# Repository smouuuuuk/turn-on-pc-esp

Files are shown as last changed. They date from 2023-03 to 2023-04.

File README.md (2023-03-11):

# Turning ON or OFF your PC using an ESP8266

I needed a way to turn my PC On from outside my house just in case I ever need to access a file.

Firstly, I considered using the WakeOnLan protocol which would be fairly easy to set up by using a Raspberry Pi or doing some port-forwarding in my home router.

I opted for a second option, at the time I was messing around with ESP microcontrollers and wanted to work with one of those. So I searched around for ways to do this and found [noisycarlos's video](https://www.youtube.com/watch?v=rV2b7UrGHbk&t=4s) which had a link to his [website](https://noisycarlos.com/project/how-to-turn-your-computer-on-and-off-remotely/) with code and a schematic for the circuit.

Much of the code is based on his code. I tweaked it a bit so instead of having to send commands to the ESP8266 I could do it through a WebServer hosted by the microcontroller and a few buttons on it. I also added comments to the code and changed a part of the circuit schematic.

I used an ESP8266 microcontroller that I had laying around, the D1 Mini NodeMCU ESP8266-12F from AZ-Delivery.

You first need to know how the pins on the motherboard work whenever you turn it on or reset it by pressing the buttons on your case.

When you press the power button on your PC's case it shortcircuits both power pins on the motherboard and that's when the PC turns ON. It's the same thing for the reset button. Knowing this I needed a way to make this connection by sending a signal from the ESP8266.

In his video, noisycarlos uses some optocouplers to make the shortcircuit between the pins but I decided I wanted to try using some relays, the mechanical part of it and the sound they make when they close the circuit is just that satisfying.

So I bought a few relays. I tested if first at the shop by hooking it up to two 1.5V batteries in series and it worked so I thought it would be fine with the 3.3V that come out of the microcontroller GPIO pins.

I plugged it into one of the GPIO pins and it didn't work, it did work on the 3.3V pin though. This happened because I didn't take into account the maximum current the GPIO pins can output (12mA) which is not enough to activate the relay.

After this I decided to use Optocouplers, these components are typically used in low power applications, and due to their non-mechanical nature they're usually longer lasting than a relay. Searching for one that would fit my requirements I ended up getting a few 4N25, which is able to operate with those 12mA coming from the GPIO pins.

For the power/reset pins I connect one of the GPIO pins to the input of the 4N25 and the other to GND. At the output I connect both cables that go to the motherboard pins. When I pull the GPIO pin to HIGH and current flows through the optocoupler both ends at the output are connected thus creating a shortcircuit, emulating a button press.

The principle for reading the state of the Power LED is the same but the other way around, the LED pins from the motherboard are the ones activating or deactivating the 4N25 and at the output of the IC I hava the 3.3V pin connected to one of the outputs of the IC and an Input pin from the ESP8266 at the other output, this way it knows when the LED light is ON or OFF.

# Connections

The pins I used are the following:
* D1 (GPIO5)  -  Pin used to read if the Power LED is ON or OFF
* D2 (GPIO4)  -  Pin used to turn ON or OFF the Power LED on the PC's case
* D5 (GPIO14) -  Pin used to activate the Reset signal for the PC
* D7 (GPIO13) -  Pin used to activate the Power signal for the PC

A diagram of the circuit can be seen here:

Final-Schematic

I've also made a custom PCB and a simple 3D case to enclose everything inside it. Feel free to tweak them however you like!

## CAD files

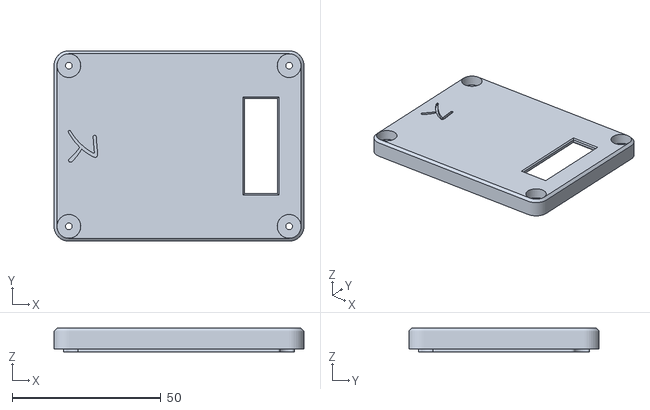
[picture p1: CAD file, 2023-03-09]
files/3D_Case/Tapa.stl
84.0 x 64.0 x 8.00

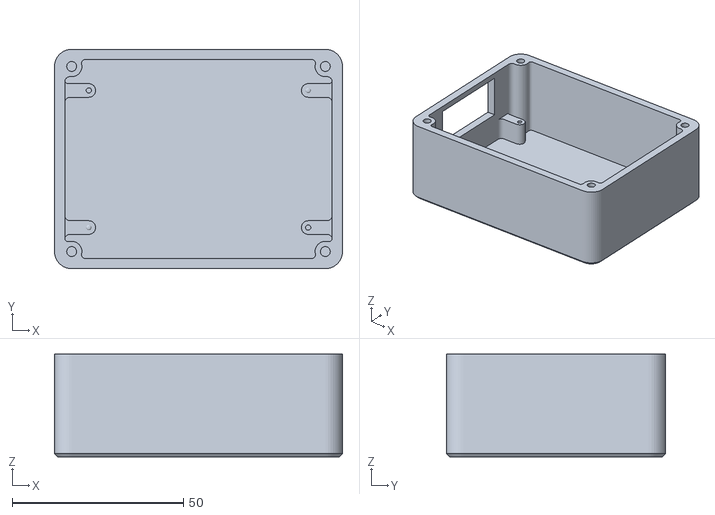
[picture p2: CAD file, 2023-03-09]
files/3D_Case/Caja.stl
84.0 x 64.0 x 30.0

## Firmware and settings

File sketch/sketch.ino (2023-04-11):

/* 
 * Turning on your PC using an ESP8266 Microcontroller
 * Created March 6, 2023 by Alexander Cabello
 */

#include <ESP8266WiFi.h>
#include <WiFiClient.h>
#include <ESP8266WebServer.h>
#include <ESP8266HTTPClient.h>
#include <ESP_Mail_Client.h>

#include "secrets.h"            // files with credentials, the following variables are taken from the secrets.h file:
                                // SECRET_SSID  - SSID from the AP used to connect to the Internet
                                // SECRET_PWD   - Password to access the network
                                // SECRET_REALM - 
                                // SECRET_LOGIN  - User to authenticate in the WebServer
                                // SECRET_PASS  - Password to authenticate in the WebServer

ESP8266WebServer server(80);    // WebServer will be hosted on port 80

WiFiClient wifiClient;

SMTPSession smtp;

const int powerButtonPin = 13,  // pins needed for the project
          resetButtonPin = 14,
          ledInPin = 5,
          ledOutPin = 4;

int powerPins[] = {powerButtonPin, resetButtonPin};   // pins that will act as the power and restart "buttons"

const int buttonNormalPressTime = 500,  // press the button for 500ms
          buttonForcePressTime = 5000;  // press the button for 5 seconds

int lastOn = 0,     // last time the LED light turned on (since the start)
    lastOff = 0;    // last time the LED light turned off (since the start)

int statePC = 0;    // 0=Off, 1=On, 2=Sleep

const String stateColors[] = {"#f03131", "#5cdf28", "#3743f0"};  // rgb colors in hexadecimal format that will represent the different states of the PC

int prevLightStatus = 0;       // 0=Off, 1=On, not the immediate value of the LED, will be useful to determine if there's been a change from its previous state

int timeToRelease = 0;         // time at which the currently pressed button will have to be released
int currentButtonPressed = 0;  // 0=Nothing, 1=Power On/Off/Force, 2=Reboot

String currentPublicIP = "";
const int waitTimeCheckIP = 4 * 3600 * 1000;  // will send and API request every 4 hours
int timeToCheckPublicIP = 0;   // time at which the API request will be sent

/**
 * "Presses" the button by putting the pin assigned to the power button to its HIGH state
 * Takes in one parameter - time - which defines for how long the power button will be pressed
 */
void pressPowerButton(int time){
  digitalWrite(powerPins[currentButtonPressed-1], HIGH);
  // the time at which the button will have to be released is stored
  timeToRelease = millis() + time;
}

/**
 * Does the same as the previous function but for the reset button by putting the pin assigned to the reset button to its HIGH state
 */
void pressResetButton(int time){
  digitalWrite(powerPins[currentButtonPressed-1], HIGH);
  timeToRelease = millis() + time;
}

/**
 * Checks if there is a pressed button and if the current time has reached the time at which the button has to be released
 * If so, the pin assigned to the pressed button is pulled to its LOW state
 */
void checkIfNeedToRelease(){
  if (currentButtonPressed && millis() >= timeToRelease){
    digitalWrite(powerPins[currentButtonPressed - 1], LOW);
    currentButtonPressed = 0;
  }
}

/**
 * Checks the present state of the Power LED Light coming from the Motherboard
 * Also stores the last time at which the LED turned ON or OFF (implying a transition from one to the other)
 */
void checkLEDPowerLight(){
  int stateLED = digitalRead(ledInPin);
  // outputs its current state to the output pin going to the LED of the button on the case
  digitalWrite (ledOutPin, stateLED);
  // if it's ON and it was OFF in its previous state
  if (stateLED && !prevLightStatus){
    lastOn = millis();
  // if it's OFF and it was ON in its previous state
  } else if (!stateLED && prevLightStatus) {
    lastOff = millis();
  }
  // current state stored for comparison in the next loop
  prevLightStatus = stateLED;
  checkStatusChange(stateLED);
}

/**
 * Checks the current state of the PC
 * The state can be one of the following: 0 (OFF), 1 (ON), 2 (SLEEP)
 * Takes one parameter - stateLED - which defines the current state of the LED
 */
void checkStatusChange(int stateLED){
  // necessary for when the code starts to run, otherwise it would define the state of the PC as SLEEP at the start
  if(lastOn != 0 && lastOff != 0){
    // if the LED has neither been ON or OFF for more than 4 seconds it must mean it's in SLEEP which goes from ON to OFF every second
    if((millis() < lastOn + 4000) && (millis() < lastOff + 4000)){
      // if the previous state is different then we announce the change it on the Serial Monitor
      if (statePC != 2) Serial.println("State: Sleep");
      statePC = 2;
      return;
    }
  }
  // if it's not in SLEEP it must be either ON or OFF
  // we can just use the current state on the LED to determine that
  if(stateLED){
    if (statePC != 1) Serial.println("State: On");
    statePC = 1;
  } else {
    if (statePC != 0) Serial.println("State: Off");
    statePC = 0;
  }
}

/**
 * Serves the root page to the client accessing the WebServer
 * Will vary the color of a small portion in the background indicating the current state of the PC
 */
void handleRoot(){
  // we include all of the html code on a String which will be sent to the client
  String rootPage;
  rootPage += "<html style=\"font-family:Arial,Helvetica,sans-serif; box-sizing: border-box; display: grid; place-items: center; height: 100vh; padding: 1em; background-color: ";
  rootPage += stateColors[statePC];
  rootPage += "\"> <head> <title>Manage PC</title> </head> <body style=\"height:100%;width:100%;display:grid;place-items:center;padding:0;margin:0; border: 1px solid black; background-color: white;\"> <a href=\"onoff\" style=\"font-size:3em;color:#000;text-decoration:none;height:100%;width:100%;border-bottom:2px solid #000;display:grid;place-items:center\" onmouseover='this.style.backgroundColor=\"#000000\",this.style.color=\"white\"' onmouseout='this.style.backgroundColor=\"\",this.style.color=\"black\"'>ON/OFF</a> <a href=\"reboot\" style=\"font-size:3em;color:#000;text-decoration:none;height:100%;width:100%;border-bottom:2px solid #000;display:grid;place-items:center\" onmouseover='this.style.backgroundColor=\"#000000\",this.style.color=\"white\"' onmouseout='this.style.backgroundColor=\"\",this.style.color=\"black\"'>RESTART</a> <a href=\"force\" style=\"font-size:3em;color:#000;text-decoration:none;height:100%;width:100%;border-bottom:2px solid #000;display:grid;place-items:center\" onmouseover='this.style.backgroundColor=\"#000000\",this.style.color=\"white\"' onmouseout='this.style.backgroundColor=\"\",this.style.color=\"black\"'>FORCE</a> </body> </html>";
  server.send(200, "text/html", rootPage);
}

/**
 * Serves the onoff page to the client accessing the WebServer
 * If no button is currently pressed it will call the function to press the Power Button to turn the PC ON or OFF
 * At the end, it redirects the client to the root page
 */
void handleOnOff(){
  server.sendHeader("Location", String("/"), true);
  if (!currentButtonPressed){
    currentButtonPressed = 1;
    pressPowerButton(buttonNormalPressTime);
  }
  server.send ( 302, "text/plain", "");
}

/**
 * Serves the reboot page to the client accessing the WebServer
 * If no button is currently pressed it will call the function to press the Reset Button
 * At the end, it redirects the client to the root page
 */
void handleReboot(){
  server.sendHeader("Location", String("/"), true);
  if (!currentButtonPressed){
    currentButtonPressed = 2;
    pressResetButton(buttonNormalPressTime);
  }
  server.send ( 302, "text/plain", "");
}

/**
 * Serves the force page to the client accessing the WebServer
 * If no button is currently pressed it will call the function to press the Power Button and hold it for the specified time
 * At the end, it redirects the client to the root page
 */
void handleForce(){
  server.sendHeader("Location", String("/"), true);
  if (!currentButtonPressed){
    currentButtonPressed = 1;
    pressPowerButton(buttonForcePressTime);
  }
  server.send ( 302, "text/plain", "");
}

/**
 * If the client tries to access a location that doesn't exist they will be redirected to the root page
 */
void handleNotFound(){
  server.sendHeader("Location", String("/"), true);
  server.send ( 302, "text/plain", "");
}

void checkIfNeedToCheckIP() {
  if (millis() >= timeToCheckPublicIP){
    HTTPClient http;
    http.begin(wifiClient, "https://api.ipify.org");
    int httpCode = http.GET();
    if (httpCode > 0) {
      String payload = http.getString();
      Serial.println(payload);
      if (payload != currentPublicIP){
        currentPublicIP = payload;
        notifyPublicIPChange(currentPublicIP);
    }
    http.end();
    }
    timeToCheckPublicIP += waitTimeCheckIP;
  }
}

void notifyPublicIPChange (String newIP){
  ESP_Mail_Session session;
  session.server.host_name = "smtp.gmail.com" ;
  session.server.port = 465;
  session.login.email = SECRET_EMAIL_SENDER;
  session.login.password = SECRET_APP_PASS;
  session.login.user_domain = "";
  
  SMTP_Message message;
  message.sender.name = "ESP8266";
  message.sender.email = SECRET_EMAIL_SENDER;
  message.subject = "ESP8266 Testing Email";
  message.addRecipient("Receiver",SECRET_EMAIL_RECIPIENT);
  String textMsg = newIP;
  message.text.content = textMsg.c_str();
  message.text.charSet = "us-ascii";
  message.text.transfer_encoding = Content_Transfer_Encoding::enc_7bit;

  if (!smtp.connect(&session)) return;
  if (!MailClient.sendMail(&smtp, &message)) Serial.println("Error sending Email, " + smtp.errorReason());
}

void setup(){
  Serial.begin(115200);
  Serial.println("");

  // pin initialization
  for (int i=0; i<sizeof(powerPins); i++){
    pinMode(powerPins[i], OUTPUT);
    digitalWrite(powerPins[i], LOW);
  }
  
  pinMode(ledOutPin, OUTPUT);
  digitalWrite(ledOutPin, LOW);
  pinMode(ledInPin, INPUT);

  // connection to the AP
  WiFi.mode(WIFI_STA);
  WiFi.begin(SECRET_SSID, SECRET_PWD);
  Serial.print("Connecting");
  
  // wait for connection
  while (WiFi.status() != WL_CONNECTED) {
    delay(500);
    Serial.print(".");
  }

  Serial.println("");
  Serial.print("Connected to ");
  Serial.println(WiFi.SSID());
  Serial.print("IP address: ");
  Serial.println(WiFi.localIP());

  // functions that determine what happens when the client asks for a certain page, in this case we have a root page and three more pages for the different actions (turning on/off the PC, restarting it or forcing it to shut down)
  // when accessing the root page or any other directory we'll be prompted with a pop-up to authenticate ourselves (if we haven't authenticated ourselves previously or some time has passed)
  server.on("/", []() {
    // if the user/password combination don't match the defined credentials in the secrets.h file it will display a fail response
    // if it matches it continues with the code
    if (!server.authenticate(SECRET_LOGIN, SECRET_PASS)){
      return server.requestAuthentication(DIGEST_AUTH, SECRET_REALM, "Authentication Failed");
    }
    handleRoot();
  });
  server.on("/onoff", handleOnOff);
  server.on("/reboot", handleReboot);
  server.on("/force", handleForce);
  server.onNotFound(handleNotFound);
  server.begin();
}

void loop(){
  checkIfNeedToRelease();
  checkLEDPowerLight();
  checkIfNeedToCheckIP();
  server.handleClient();
}

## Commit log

2023-03-03 First Working Prototype
2023-03-06 Fixed PC State Monitoring
    [sketch.ino]
